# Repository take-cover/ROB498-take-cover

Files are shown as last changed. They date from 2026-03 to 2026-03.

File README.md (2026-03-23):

# ROB498: Take Cover

This is the repo for team Take Cover for ROB498

# General Flight Exercise Setup

 1. Vicon: make sure ROS_DOMAIN_ID = 1; ask TA to turn on vicon system;
 2. Have laptop be connected to ROB498 wifi; then, connect to Jetson via ssh
 3. `ros2 topic echo /vicon/ROB498_Drone/ROB498_Drone`
 4. `ros2 launch realsense2_camera rs_launch.py`
 5. MAVROS: go to directory where mavros.launch.py is located (haven't made it a package yet), `ros2 launch mavros.launch.py`
 6. `python3 comm_node.py`
 7. `ros2 service list -t` --> then can just call the services
 8. to call a service: e.g.) `ros2 service call /rob498_drone_1/comm/launch std_srvs/srv/Trigger`

 ### How to SSH to Jetson Nano on Local Device
 1. Connect to TP-Link_ROB498 Network (password is rob498drones)
 2. `ssh jetson@10.42.0.121` (password is jetson)

 ### How to Connect to QGC Wirelessly
 1. Must be connected to TP-Link_ROB498 Network
 2. On Jetson, run `ros2 launch mavros.launch.py gcs_url:=udp://@<ip-address-on-local-computer>:14550`
 3. In QGroundControl, Application Settings -> Comm Links -> Add New Link

 QGC Wireless Connection Example

 ### How to Change Network on Jetson via CLI
 0. if connected via wire: ssh jetson@192.168.55.1
 1. `nmcli device` to see which network wlan0 is currently connected to
 2. `nmcli device wifi list` to see which networks are available
 3. `sudo nmcli device wifi connect "YOUR_SSID_NAME" password "YOUR_WIFI_PASSWORD"` password not needed if previously connected to network

 ### IPs:
 1. UofT: jetson@100.66.147.255 (may change, use ifconfig to check)
 2. TP-Link_ROB498: jetson@10.42.0.101

 ### Installing Propellors
QGC Propellor Directions
Propellor Directions

### Frames
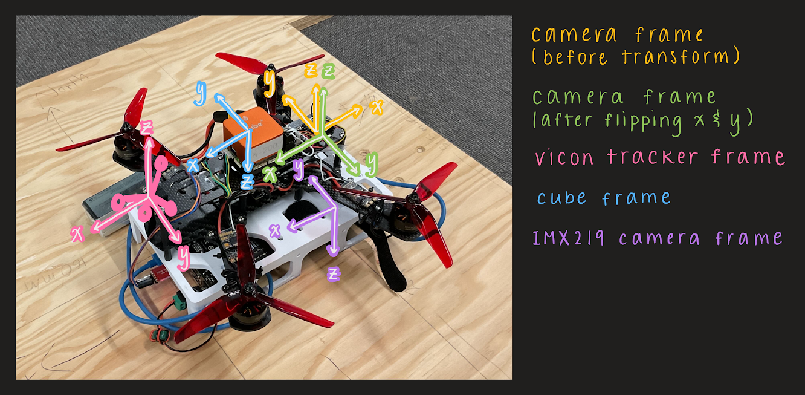
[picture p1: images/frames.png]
Frames

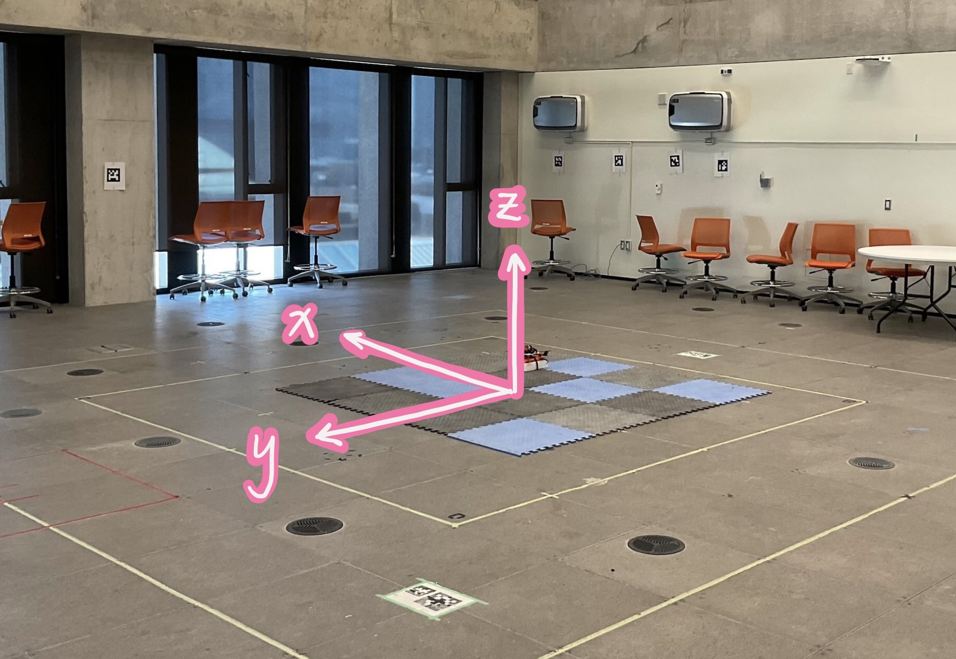
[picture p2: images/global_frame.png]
Global Vicon Frame


### Set Time on Jetson to Current Time
1. Change to UofT network
2. `sudo ntpdate pool.ntp.org`
3. `date` returns the date

## Flight Exercise 2 Setup
1. `ros2 launch realsense2_camera rs_launch.py`
2. `ros2 topic echo /vicon/ROB498_Drone/ROB498_Drone`, validate that x, y, z directions are expected
3. `ros2 launch mavros.launch.py gcs_url:=udp://@<ip-address-on-local-computer>:14550`
4. `python3 comm_node.py`
5. `ros2 service call /rob498_drone_1/comm/launch std_srvs/srv/Trigger`
5. `ros2 service call /rob498_drone_1/comm/test std_srvs/srv/Trigger`
6. `ros2 service call /rob498_drone_1/comm/land std_srvs/srv/Trigger`

### Positioning the Drone for Vicon
1. Install Vicon marker in the orientation as shown under [Frames](#frames)
2. Place drone so that front is facing windows (and back is facing the whiteboard); line up Vicon marker with global vicon frame

# SARDine Setup

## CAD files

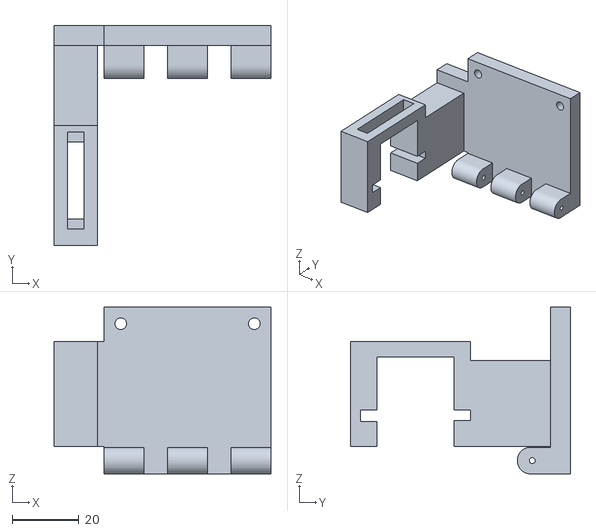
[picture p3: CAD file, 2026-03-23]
prints/holder-1.stl
65.0 x 66.0 x 50.0

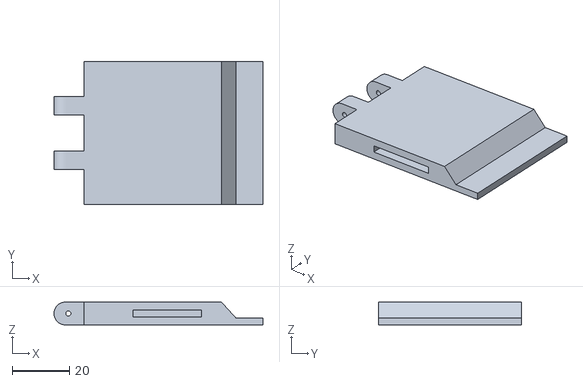
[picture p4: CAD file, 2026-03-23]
prints/flaps-1.stl
72.9 x 50.0 x 8.00

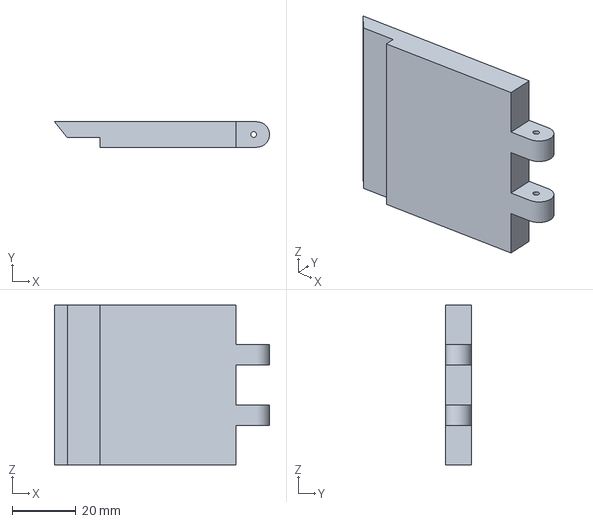
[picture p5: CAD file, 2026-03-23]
prints/flaps-2-fixed.3mf
67.4 x 8.00 x 50.0 mm

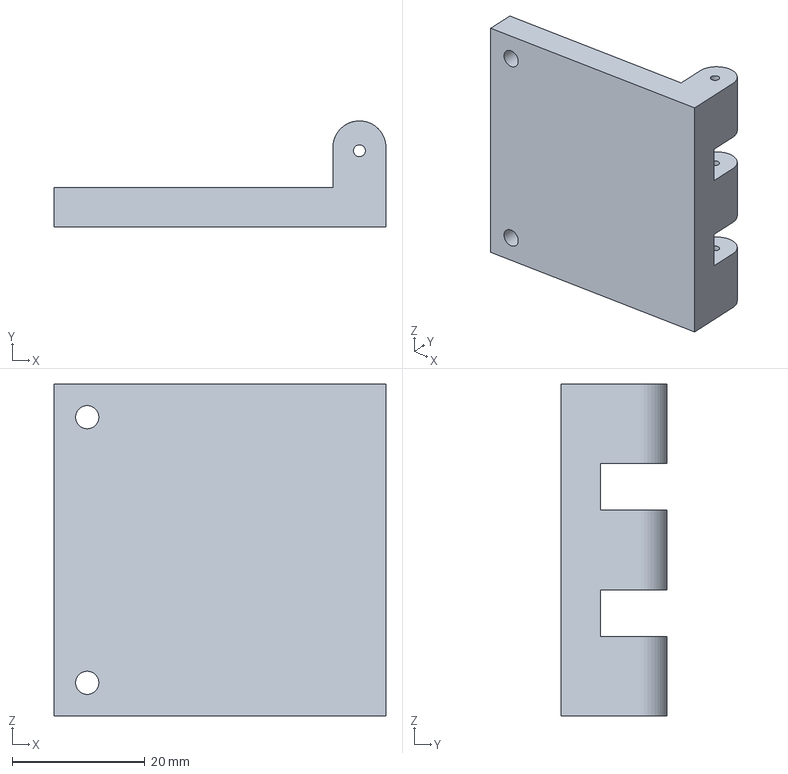
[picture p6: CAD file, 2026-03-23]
prints/holder-2-fixed.3mf
50.0 x 16.0 x 50.0 mm

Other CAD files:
prints/holder-1-fixed.3mf
prints/flaps-1-fixed.3mf
prints/flaps-2.stl
prints/holder-2.stl

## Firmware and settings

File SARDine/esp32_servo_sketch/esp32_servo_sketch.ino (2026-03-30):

#include <ESP32Servo.h>

Servo myservo;
const int servoSwitchPin = 25;   
const int ledSwitchPin = 26;
const int servoPin = 33; // Output for servo control
const int ledPin = 32;    // Output to LED

void setup() {
  Serial.begin(115200);

  // Configure Inputs
  pinMode(servoSwitchPin, INPUT);
  pinMode(ledSwitchPin, INPUT);
  
  // Configure Output
  pinMode(ledPin, OUTPUT);

  // Servo Setup
  ESP32PWM::allocateTimer(0);
  myservo.setPeriodHertz(50);
  myservo.attach(servoPin, 500, 2400); 
}

void loop() {
  // 1. Continuous Servo Logic
  if (digitalRead(servoSwitchPin) == HIGH) {
    myservo.write(0);
  } else {
    myservo.write(90);
  }

  // 2. LED Logic 
  if (digitalRead(ledSwitchPin) == HIGH) {
    digitalWrite(ledPin, HIGH); // Turn LED ON
  } else {
    digitalWrite(ledPin, LOW);  // Turn LED OFF
  }

  // Small delay for stability
  delay(20); 
}

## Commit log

2026-03-06 add ip for wire connection; uoft ip can change
2026-03-18 fix camera node run; still failed to capture frame
2026-03-19 add aruco pose print, rename var
2026-03-23 print out pose coordinates on detection
2026-03-23 add imx frame to readme
2026-03-23 add print files for drop mechanism
    [flaps-1-fixed.3mf, flaps-1.stl, flaps-2-fixed.3mf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]
2026-03-23 update camera to marker offset
2026-03-27 now sends physical signal to gpio pin to turn servo
2026-03-30 clean up breadboard wiring, update pin mapping
2026-03-30 update servo actuation, var name
2026-03-30 add tracking led control
